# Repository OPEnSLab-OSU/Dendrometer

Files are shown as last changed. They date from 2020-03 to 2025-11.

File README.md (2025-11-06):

<p align="center">
    
  </a>
</p>

<h3 align="center">Dendrometer</h3>



## Introduction
The Dendrometer is an ongoing project that strives to enable ecological researchers and/or care-takers of grape plants to be able to effectively measure diurnal fluctuations in grape vines. Such information can be crucial for producing market-ideal grapes, as the shrinkage and growth of the vines are important indicators of when the plant is in need of water. Learn more about the design and outcomes on our <a href="https://github.com/OPEnSLab-OSU/OPEnS-Lab-Home/wiki/Dendrometer">Dendrometer Lab Wiki</a>. 

## Key Features
  - Data is collected and written to a SD card every 15 minutes, allowing the system to operate for long durations without human intervention
  - Devices can wirelessly report data back to a remote server by communicating with an internet-connected "hub" device
  - Magnetic encoder ([AS5311](https://ams.com/documents/20143/36005/AS5311_DS000200_2-00.pdf)) has a resolution of ~488nm with an extremely low temperature dependency (ideal for outdoor use)
  - Integration with [Loom](https://github.com/OPEnSLab-OSU/Loom-V4), which will allow this device to support plug-and-play functionalities with integrated sensors

## Directory 
### PCB: 
Printed circuit board (PCB) design files for the nodes. 
### src: 
Contains all of the code used on the dendrometer.
LoRa: Contains the source code for the node sensors and the LTE hub. This uses LoRa batch uploading which will upload all of the collected data at set intervals.
LoRa Non Batch: Contains the source code for the node sensors and the LTE hub. This will only upload ONE packet of data at set intervals. All of the data is still saved on SD card.
WiFi: Contains the source code for the WiFi connected nodes.

## Relevant Documents
* [User Manual](https://docs.google.com/document/d/1OHKa2jYamG2kPEfxrQMzi3MNHZGgkPIG/)
* [HardwareX Paper](https://www.sciencedirect.com/science/article/pii/S246806722100078X)
* [Troubleshooting Guide](https://docs.google.com/document/d/1E4zUMmSh5PVmP7RXUqQrh7S9IGuxQKPj5EQ5KcT2HYE/edit?usp=sharing)
* [Mechanical Assembly Guide](https://docs.google.com/document/d/1LzM_XnqVP9GkIqY2_pnTvdrFFe5u78ZPXJizvT70y4o/edit?usp=sharing)
* [Electronics Assembly Guide](https://docs.google.com/document/d/1BaNuNSJrL86lxKixB8chgZGySgj0bhYSMtVzJu6EDW4/edit?usp=sharing)
* [MongoDB Dashboard Guide](https://docs.google.com/document/d/1PlT9hrC62OXXhL8AD17e3FiPCwlHFJaZIvXCRnmihIE/edit?usp=sharing)
* [Installation Guide (Outdated)](https://docs.google.com/document/d/1GR2qeMWASApCwk-RbZwvsvWmB1qEz0QU8RcxwjgoDQY/edit?usp=sharing)

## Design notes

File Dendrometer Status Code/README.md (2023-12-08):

# DendrometerStatus
This code was written by Dajeong Kim from UBC team. This code connects to MongoDB and sends email reports of alignment, battery status, and data point plots

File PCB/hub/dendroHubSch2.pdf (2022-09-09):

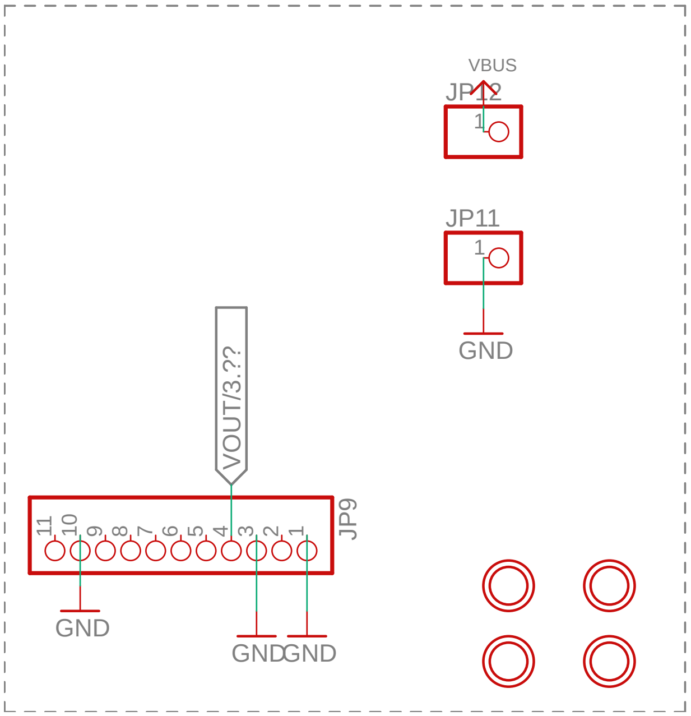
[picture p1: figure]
GND; GNDGND; VBUS 1110; JP12 VOUT/3.??

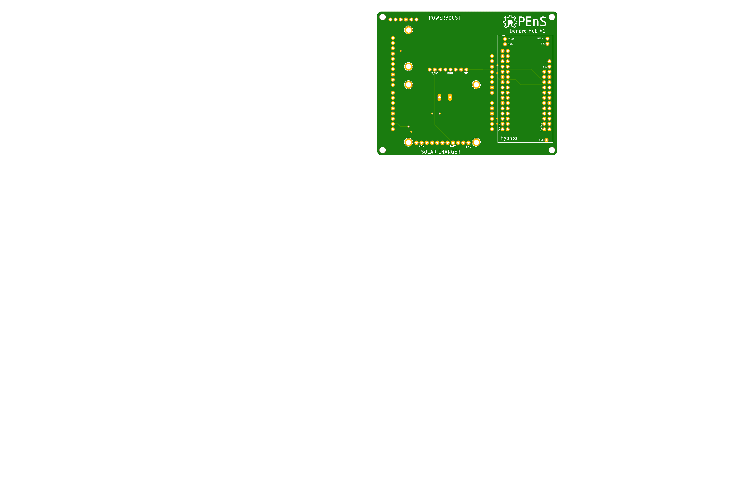
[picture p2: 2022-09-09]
PCB/hub/dendHub_top.png

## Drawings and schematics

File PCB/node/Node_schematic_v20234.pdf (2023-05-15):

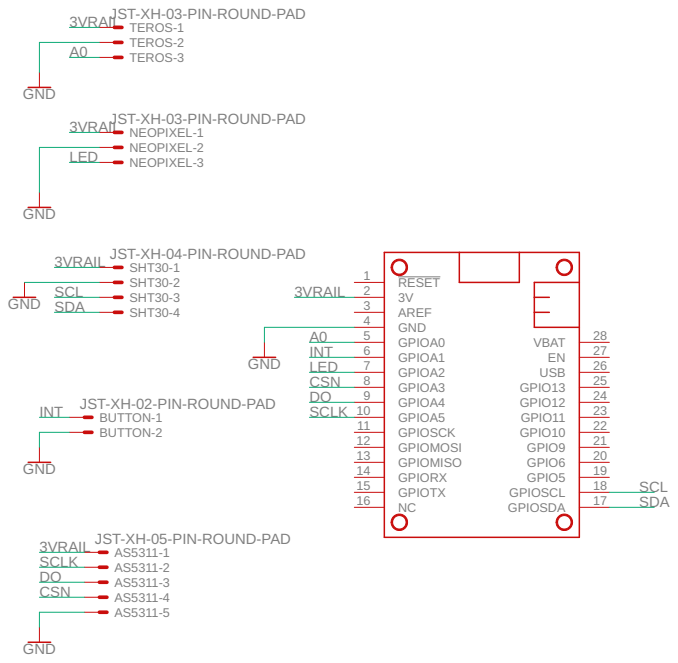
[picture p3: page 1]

JST-XH-03-PIN-ROUND-PAD
TEROS-1
TEROS-2
TEROS-3

NEOPIXEL-1
NEOPIXEL-2
NEOPIXEL-3

JST-XH-02-PIN-ROUND-PAD
BUTTON-1
BUTTON-2

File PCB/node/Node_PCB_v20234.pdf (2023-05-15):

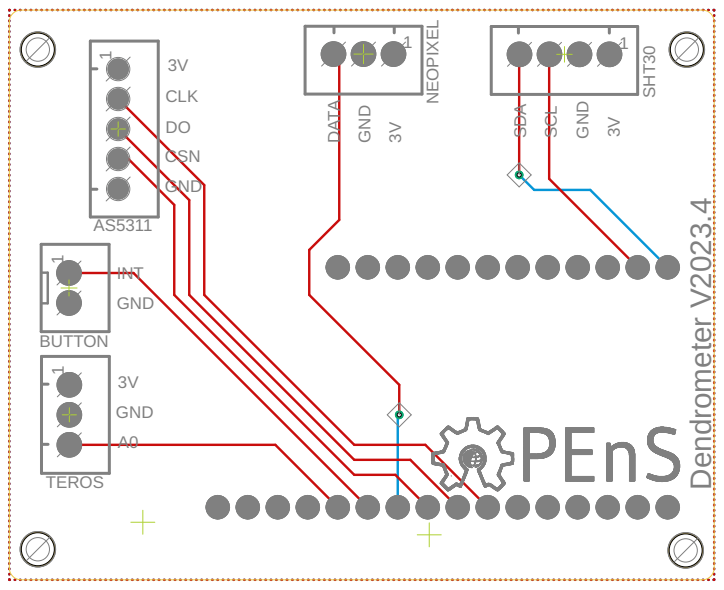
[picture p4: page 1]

Dendrometer V2023.4 1 1 1 1 1 GND GND GND INT 3V3V DATA SCL SDA GND CSN DOCLK 3V GND A03V BUTTON NEOPIXEL SHT30 AS5311 TEROS

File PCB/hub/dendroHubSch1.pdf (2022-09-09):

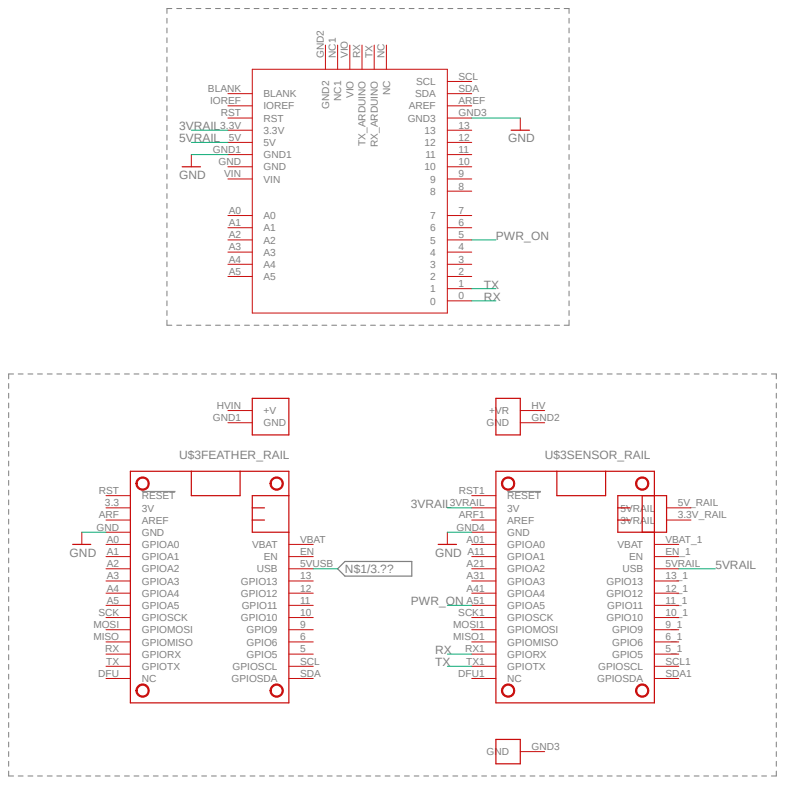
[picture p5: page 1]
GND; BLANK BLANK; IOREF IOREF; RST RST; GND1 GND1; GND GND; VIN VIN; GND² GND² NC¹ NC¹ VIO VIO TX_ARDUINO RX RX_ARDUINO TX NC NC; SCL; SCL SDA; SDA; AREF; AREF GND3; GND3; 0 RESET RST; AREF ARF; EN GND GND; GPIO5; 5 GPIO6; 6 GPIO9; 9 GPIO10; 10 GPIO11; 11 GPIO12; 12 GPIO13; 13 GPIOA0 A0; GPIOA1 A1; GPIOA2 A2; GPIOA3 A3; GPIOA4 A4; GPIOA5 A5; GPIOMISO MISO; GPIOMOSI MOSI; GPIORX RX; GPIOSCK SCK; GPIOSCL; SCL GPIOSDA; SDA GPIOTX TX; NC DFU; USB; 5VUSB; VBAT; VBAT U$3FEATHER_RAIL; RESET RST1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

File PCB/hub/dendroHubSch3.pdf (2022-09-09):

# JP1 N$1/1.?? VOUT/2.??

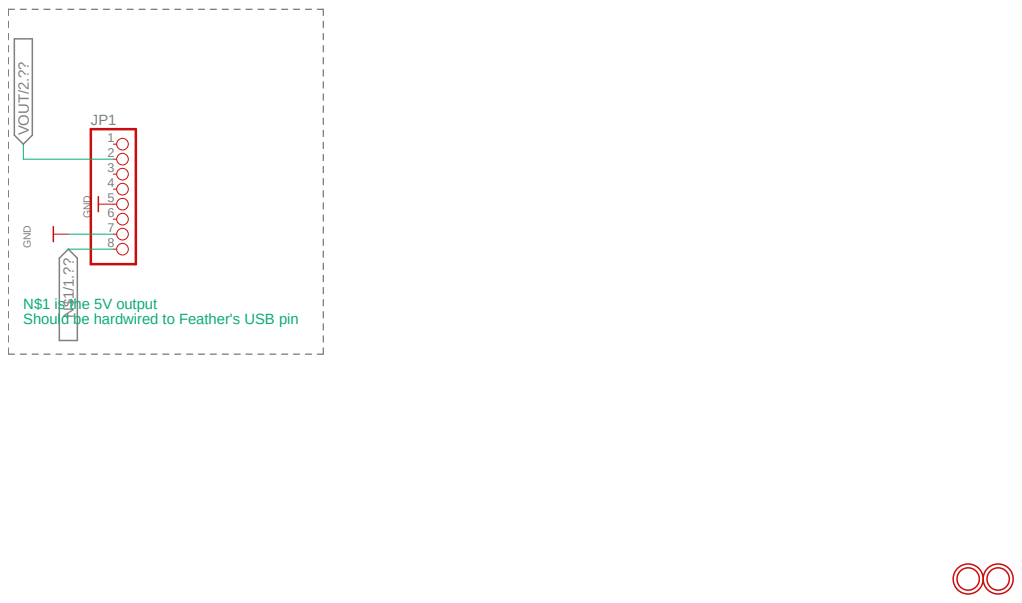
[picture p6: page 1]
GND GND

N$1 is the 5V output
Should be hardwired to Feather's USB pin

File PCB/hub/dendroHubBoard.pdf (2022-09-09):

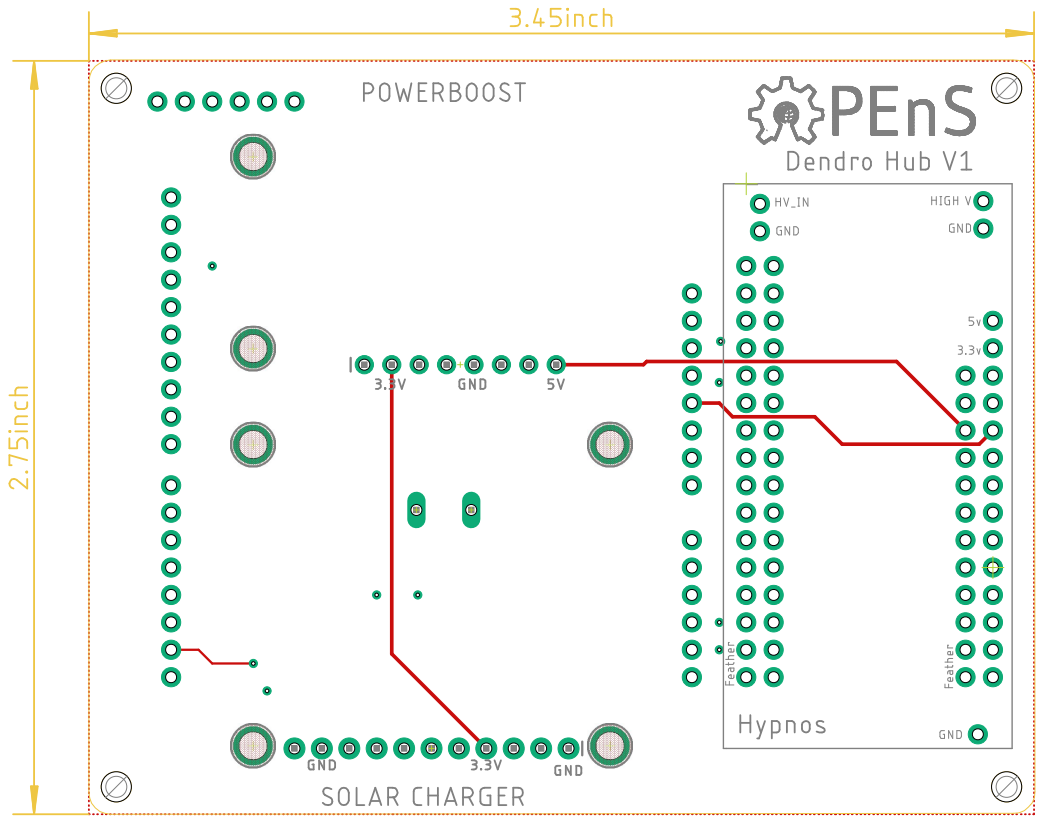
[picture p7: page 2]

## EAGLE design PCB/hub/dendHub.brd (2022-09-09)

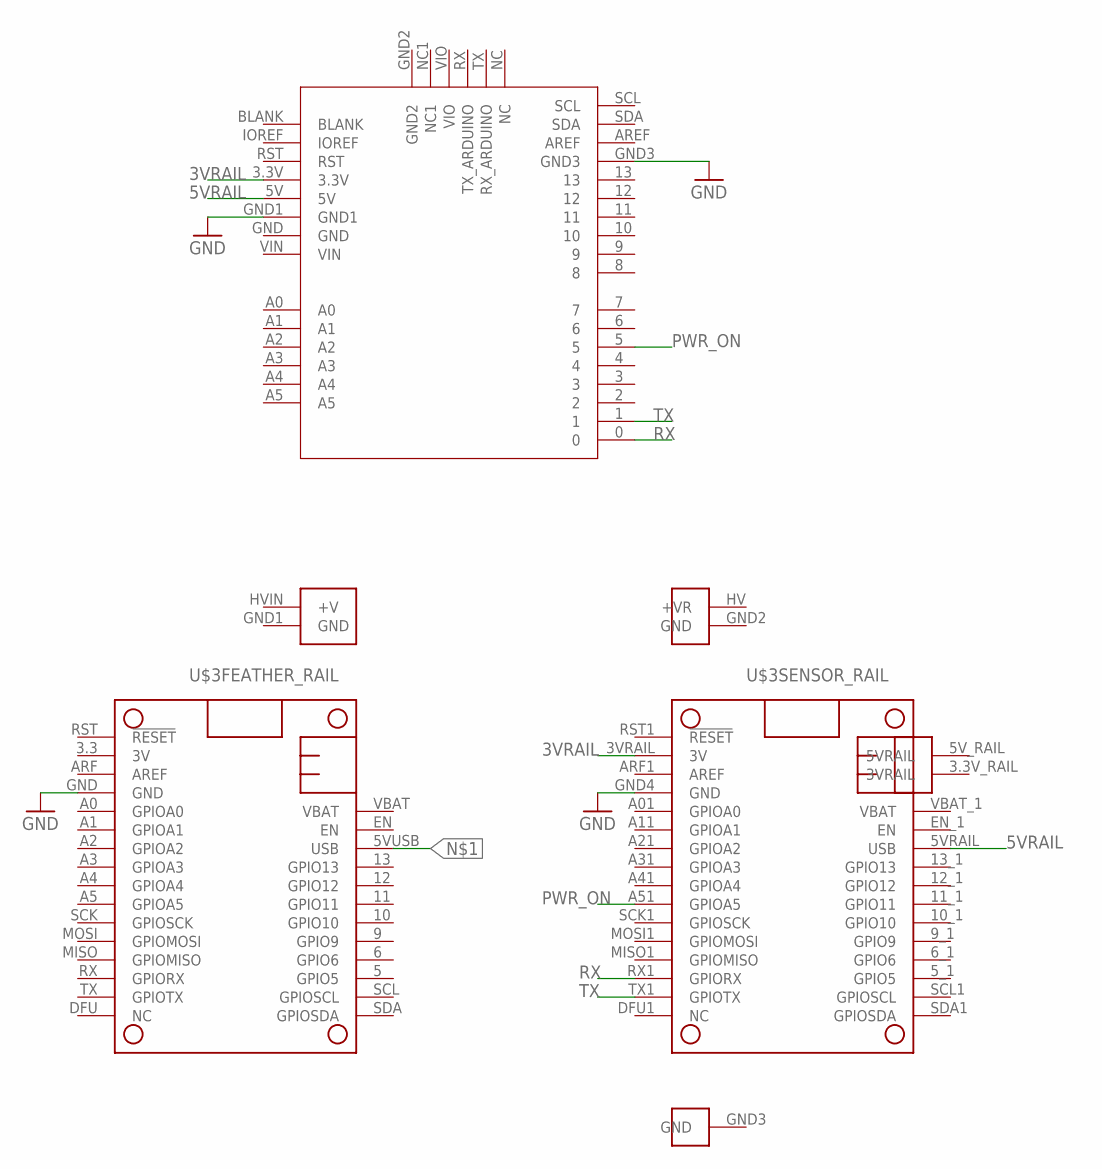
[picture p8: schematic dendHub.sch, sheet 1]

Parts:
U$1: LTE_BOARD; LTE_BOARD_FOOTPRINT
U$3: HYPNOS_V3

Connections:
3VRAIL: U$1.3.3V, U$3.3VRAIL (3V)
5VRAIL: U$1.5V, U$3.5VRAIL (USB)
GND: U$1.GND1, U$1.GND3, U$3.GND, U$3.GND4 (GND); also elsewhere on the board
unnamed 3: U$3.5VUSB (USB); also elsewhere on the board
PWR_ON: U$1.5, U$3.A51 (GPIOA5)
RX: U$1.0, U$3.RX1 (GPIORX)
TX: U$1.1, U$3.TX1 (GPIOTX)

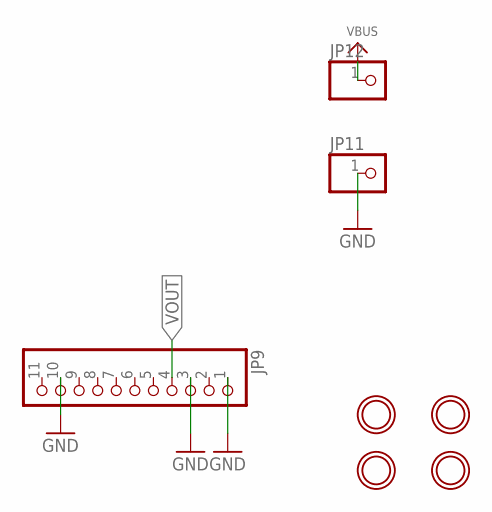
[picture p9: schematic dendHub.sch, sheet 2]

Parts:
JP9: HEADER-1X1176MIL; 1X11_ROUND_76
JP11, JP12: HEADER-1X1; 1X01_OVAL
U$45, U$46, U$47, U$48: MOUNTINGHOLE2.5; MOUNTINGHOLE_2.5_PLATED

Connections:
GND: JP9.1, JP9.3, JP9.10, JP11.1; also elsewhere on the board
VBUS: JP12.1
VOUT: JP9.4; also elsewhere on the board

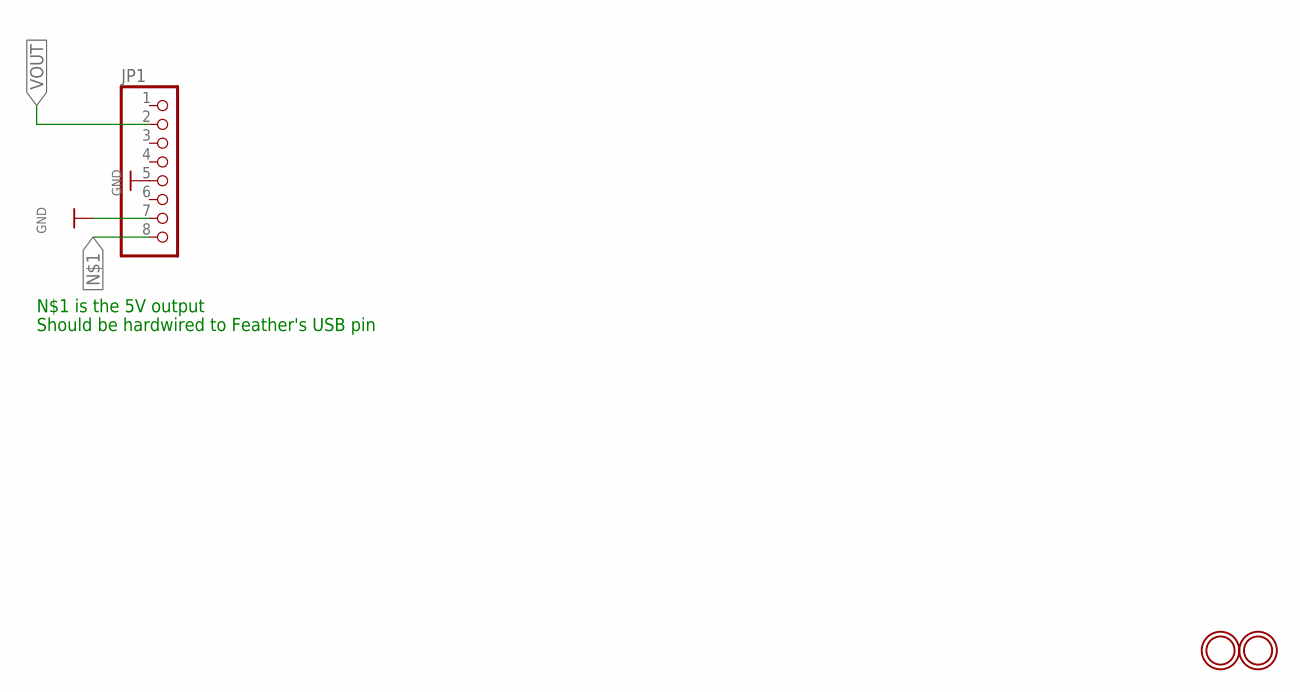
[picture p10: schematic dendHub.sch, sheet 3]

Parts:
JP1: HEADER-1X8ROUND; 1X08_ROUND
U$56, U$57: MOUNTINGHOLE2.5; MOUNTINGHOLE_2.5_PLATED

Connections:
GND: JP1.5, JP1.7; also elsewhere on the board
unnamed 3: JP1.8; also elsewhere on the board
VOUT: JP1.2; also elsewhere on the board

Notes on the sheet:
N$1 is the 5V output
Should be hardwired to Feather's USB pin

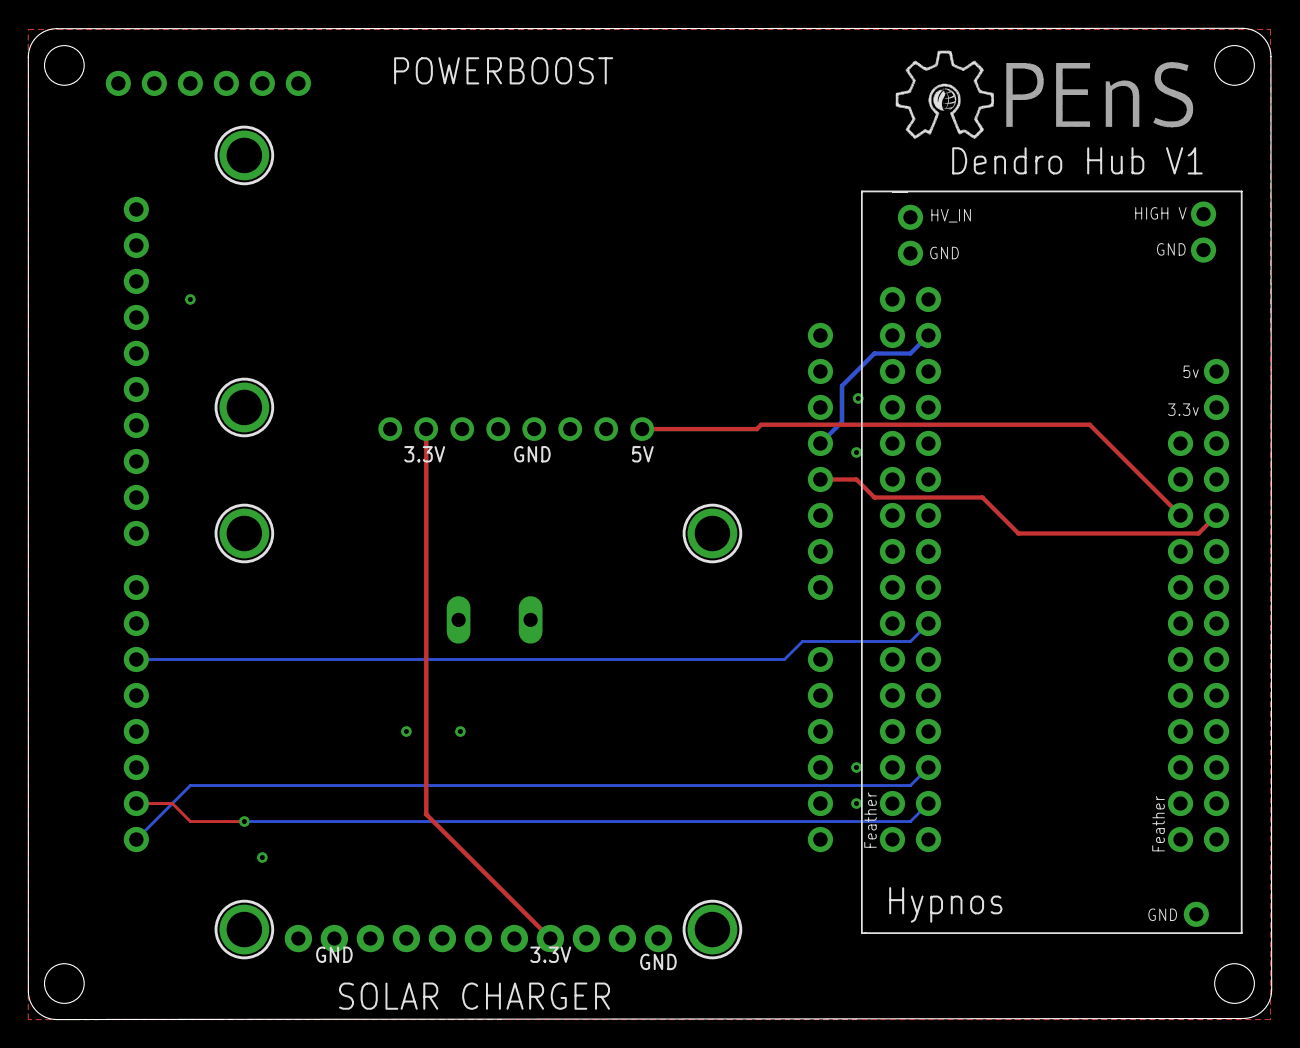
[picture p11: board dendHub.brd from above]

Board: 2 copper layers, 87.7 x 69.9 mm, 13 parts (1 on the bottom side), 8 nets.

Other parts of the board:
U$2: OPENS-LOGO

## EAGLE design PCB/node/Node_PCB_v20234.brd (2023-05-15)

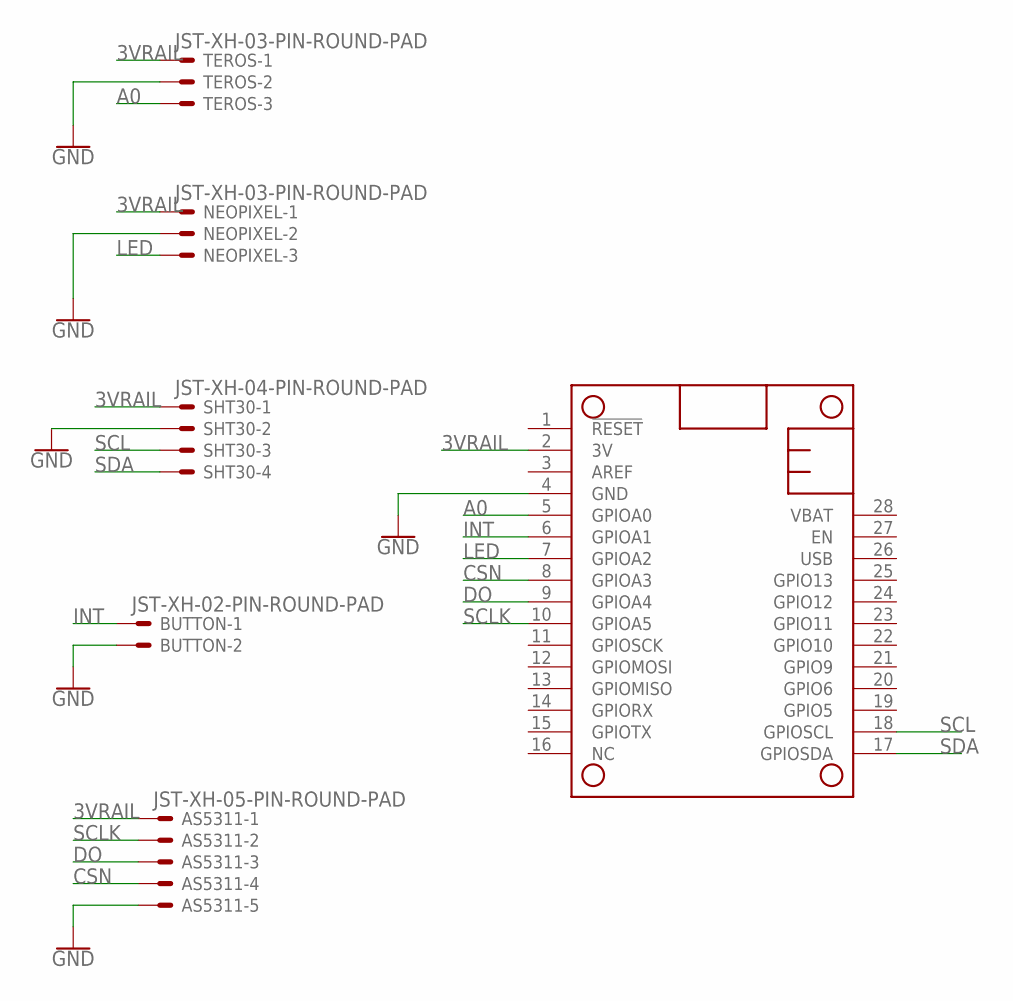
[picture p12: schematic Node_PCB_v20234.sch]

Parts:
AS5311: JST-XH-05-PIN-ROUND-PAD; JST-XH-05-PACKAGE-ROUND-PAD
BUTTON: JST-XH-02-PIN-ROUND-PAD; JST-XH-02-PACKAGE-ROUND-PAD
MS1: FEATHERWING
NEOPIXEL: JST-XH-03-PIN-ROUND-PAD; JST-XH-03-PACKAGE-ROUND-PAD
SHT30: JST-XH-04-PIN-ROUND-PAD; JST-XH-04-PACKAGE-ROUND-PAD
TEROS: JST-XH-03-PIN-ROUND-PAD; JST-XH-03-PACKAGE-ROUND-PAD

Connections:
3VRAIL: AS5311.1, MS1.2 (3V), NEOPIXEL.1, SHT30.1, TEROS.1
A0: MS1.5 (GPIOA0), TEROS.3
CSN: AS5311.4, MS1.8 (GPIOA3)
DO: AS5311.3, MS1.9 (GPIOA4)
GND: AS5311.5, BUTTON.2, MS1.4 (GND), NEOPIXEL.2, SHT30.2, TEROS.2
INT: BUTTON.1, MS1.6 (GPIOA1)
LED: MS1.7 (GPIOA2), NEOPIXEL.3
SCL: MS1.18 (GPIOSCL), SHT30.3
SCLK: AS5311.2, MS1.10 (GPIOA5)
SDA: MS1.17 (GPIOSDA), SHT30.4

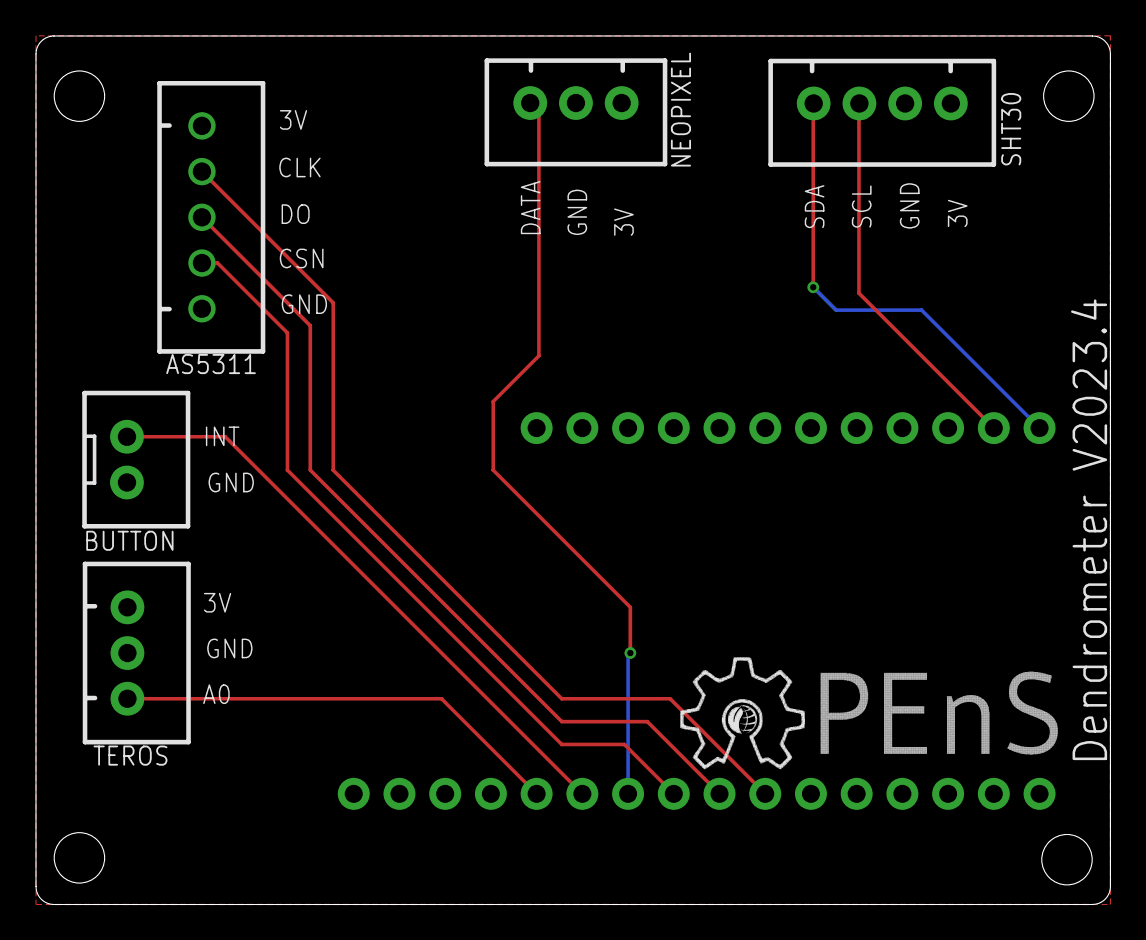
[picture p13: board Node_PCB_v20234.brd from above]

Board: 2 copper layers, 59.7 x 48.2 mm, 7 parts (0 on the bottom side), 10 nets.

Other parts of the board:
U$1: OPENS-LOGO

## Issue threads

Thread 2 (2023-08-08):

BB2 Screw/Nut on Wishbone sometimes causes issues if it touches the AS5311 board

nicholasqle, 2023-08-08:
**Describe the bug**
On one magnet sensor used, I found that there was odd behavior if the nut was touching the board. The dendrometer would be stuck on but would not function. The red lights on the feather board and the Hypnos board would all be illuminated, except for the status LED. When this happens, the device will be stuck like this and is not visible in Arduino IDE until it is reset. The device will continue working normally after the reset and the wishbone is moved off of the magnet sensor.
**Hardware in Use**
A list of all hardware currently in use
Blueberry dendrometer 2
Magnet sensor

**To Reproduce**
Steps to reproduce the behavior:
1. Position wishbone so the nut is touching the board.
2. Plug magnet sensor into Dendrometer.
3. Power on Dendrometer

**Expected behavior**
The device should be able to function normally. Perhaps better insulation on the magnet sensor is needed to prevent shorts?

nicholasqle, 2025-04-23:
**Description of steps taken to resolve them:**

- Cut solder to be more flush with sensor board
- Ensure adequete conformal coating on board to prevent shorting

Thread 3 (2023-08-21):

Timestamp issues

ejdautel, 2023-08-21:
The timestamp on some datasets are incorrect. The time will return to a certain date/time and the package number will change. UBC has consistent issues with this.

some potential causes could be the coin cell battery or the actual firmware code? I know Chet and Will were actively working on this issue, so if you could share progress we can inform UBC as well!

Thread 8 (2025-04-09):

Alignment button not responding

nicholasqle, 2025-04-09:
Date issue was identified:
2/2/2025
Who identified issue: 		Lars Rasmussen
Description of sensor model with issue: Retrofitted single spring dendrometer with 3d printed spring holder and old 1040 pelican case
Client with issue: Biosphere
Device Name: Bio8

**Description of error or issue that occurred:**
Sensor was in good working order, battery was charged, reporting through wifi was good, then alignment LED was not responding with red/yellow/green indicators when button was pressed. MongoDB Data shows that the sensor was still taking measurements but the LED was still not responding, no reported moisture damage inside case when client was asked to check, restarting the device did not resolve the issue.

**Description/list of what could be causing this issue:**

- LED is broken
- Button is broken
- Something wrong with software

**Description of steps taken to resolve them:**
The LED and button were removed and tested after the client shipped the sensor back to the lab, after testing it was found that the button was functional but the LED had gone bad. After replacing the LED and a week of running the sensor in the lab, the LED seems to be responding as intended.

**Fixed or still ongoing? Possible solutions to prevent this on future models.**

- Problem fixed and tested, sensor shipped back on 2/22/25
- Researching why LEDs might go bad, exploring other LED options if this continues in the future

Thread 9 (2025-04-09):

SD Card Failure causing data loss and unable to connect to network to upload

nicholasqle, 2025-04-09:
Date issue was identified: 	2025

Who identified issue: 		Nicholas Le

Description of sensor model with issue: 2023 Build dendrometers in 1050 cases.

Client with issue: Draga and UBC

Device Name:

**Description of error or issue that occurred:**
Data will no longer be logged on SD card or reading data from SD card is corrupt or not possible. This can cause loss of data or on the WiFi devices, being unable to connect and upload as the credentials need to be read from the SD card. Sometimes the SD card will not initialize at all.

**Description/list of what could be causing this issue:**

-Weather, heat, humidity or general wear causes the SD card to fail
-Hardware failure

**Description of steps taken to resolve them:**
-We replaced all of the sd cards on Draga devices in 2025 with [industrial SD cards](https://www.amazon.com/SanDisk-Industrial-MicroSDHC-SDSDQAF3-008G-I-Everything/dp/B085GL4LTQ?sr=8-2) which should be able to handle more extreme environments.
-Replacing the hypnos board on the UBC device 15 in March 2025 fixed an issue with initializing the SD card.
**Fixed or still ongoing? Possible solutions to prevent this on future models.**
Issue has been fixed for now but it remains to be seen whether the industrial SD cards will last longer

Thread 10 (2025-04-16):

LTE board disconnects from network

nicholasqle, 2025-04-16:
Date issue was identified:
2023
Who identified issue: 	Connor M

Description of sensor model with issue:
Hubs with SparkFun LTE Cat M1/NB-IoT Shield
Client with issue:
Draga
Device Name:
Hazelnut_hub and occasionally LB_hub
**Description of error or issue that occurred:**
Device disconnects from network. This is seen by the blue network light going out at some point during operation. Range of this occuring can be either at first startup or even weeks into a deployment.
**Description/list of what could be causing this issue:**

- Weak connection
- Some underlying issue with the Sara R410 or board
-

**Description of steps taken to resolve them:**
-Used external antenna connected to UFL. (This seemed to reduce the occurance of this problem but it still happens occasionally.
-Swap LTE board
-Forward issues to Loom team
-Used m-center program to try different AT codes and settings
-Contacted Ublox for latest firmware and Easyflash software to flash updated firmware to R410

**Fixed or still ongoing? Possible solutions to prevent this on future models.**
Still ongoing. Possibly look into using different LTE modem.

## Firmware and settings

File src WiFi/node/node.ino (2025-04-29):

#include <Loom_Manager.h> //4.6
#include <Hardware/Loom_Hypnos/Loom_Hypnos.h>
#include <Hardware/Actuators/Loom_Neopixel/Loom_Neopixel.h>
#include <Sensors/Loom_Analog/Loom_Analog.h>
#include <Sensors/Analog/Loom_Teros10/Loom_Teros10.h>
#include <Sensors/I2C/Loom_SHT31/Loom_SHT31.h>

#include <Internet/Connectivity/Loom_Wifi/Loom_Wifi.h>
#include <Internet/Logging/Loom_MongoDB/Loom_MongoDB.h>

#include "AS5311.h"

//////////////////////////
/* DEVICE CONFIGURATION */
//////////////////////////
static const uint8_t NODE_NUMBER = 1;
static const char * DEVICE_NAME = "HazelnutDendrometer_";
////Select one wireless communication option

#define DENDROMETER_WIFI

TimeSpan sleepInterval;
static const uint8_t TRANSMIT_INTERVAL = 16; // to save power, only transmit every X measurements
////Use teros 10?
//#define DENDROMETER_TEROS10
//////////////////////////
//////////////////////////

// Pins
#define AS5311_CS A3 // 9 for LB version, A3 otherwise
#define AS5311_CLK A5
#define AS5311_DO A4
#define BUTTON_PIN A1 // 11 for LB, A1 otherwise

// Loom
Manager manager(DEVICE_NAME, NODE_NUMBER);
Loom_Hypnos hypnos(manager, HYPNOS_VERSION::V3_3, TIME_ZONE::PST); // 3_2 for LB, 3_3 otherwise
// Loom Sensors
Loom_Analog analog(manager);
#ifdef DENDROMETER_TEROS10
Loom_Teros10 teros(manager, A0);
#endif
Loom_SHT31 sht(manager);
Loom_Neopixel statusLight(manager, false, false, true, NEO_GRB); // using channel 2 (physical pin A2). use RGB for through-hole LED devices. GRB otherwise.

// magnet sensor
AS5311 magnetSensor(AS5311_CS, AS5311_CLK, AS5311_DO);

// wireless
#if defined DENDROMETER_WIFI
#include "arduino_secrets.h"
Loom_WIFI wifi(manager, CommunicationMode::CLIENT, SECRET_SSID, SECRET_PASS);
Loom_MongoDB mqtt(manager, wifi, SECRET_BROKER, SECRET_PORT, MQTT_DATABASE, BROKER_USER, BROKER_PASS);
Loom_BatchSD batchSD(hypnos, TRANSMIT_INTERVAL);
#else
#warning Wireless communication disabled!
#endif

// Global Variables
volatile bool buttonPressed = false; // Check to see if button was pressed

void sleepCycle();
void ISR_RTC();
void ISR_BUTTON();

void measure();
void measureVPD();
void transmit();

void setRTC(bool);
void checkMagnetSensor();
void alignMagnetSensor();
bool checkStableAlignment();
void displayMagnetStatus(magnetStatus);
void flashColor(uint8_t r, uint8_t g, uint8_t b);

/**
 * Program setup
 */
void setup()
{

    pinMode(BUTTON_PIN, INPUT_PULLUP); // Enable pullup on button pin. this is necessary for the interrupt (and the button check on the next line)
    delay(10);
    bool userInput = !digitalRead(BUTTON_PIN); // wait for serial connection ONLY button is pressed (low reading)
    manager.beginSerial(userInput);            // wait for serial connection ONLY button is pressed
    
    hypnos.setLogName("HazelnutDendrometer_1data"); //SD card CSV file name
    hypnos.enable();
    sleepInterval = hypnos.getConfigFromSD("HypnosConfig.json");

#if defined DENDROMETER_WIFI
    wifi.setBatchSD(batchSD);
    wifi.setMaxRetries(2);
    mqtt.setMaxRetries(2);
    wifi.loadConfigFromJSON(hypnos.readFile("wifi_creds.json"));
    mqtt.loadConfigFromJSON(hypnos.readFile("mqtt_creds.json"));
    hypnos.setNetworkInterface(&wifi);
#endif
    manager.initialize();
    setRTC(userInput);

    checkMagnetSensor();
    alignMagnetSensor();

    hypnos.registerInterrupt(ISR_RTC);
}

/**
 * Main loop
 */
void loop()
{
    measure();
    if (buttonPressed) // if interrupt button was pressed, display staus of magnet sensor
    {
        displayMagnetStatus(magnetSensor.getMagnetStatus());
        delay(3000);
        statusLight.set_color(2, 0, 0, 0, 0); // LED Off
        buttonPressed = false;
    }
    transmit();
    sleepCycle();
}

/**
 * Perform all measurements for the dendrometer and put them into a packet.
 * Log to SD card.
 */
void measure()
{
    manager.measure();
    manager.package();

    measureVPD();
    magnetSensor.measure(manager);
    // Log whether system woke up from button or not
    manager.addData("Button", "Pressed?", buttonPressed);

    hypnos.logToSD();

    // delay(5000);
    // manager.display_data();
}

/**
 * Log readings from the SHT31 sensor. Also calculate and log VPD.
 */
void measureVPD()
{
    float SVP, VPD, temperature, humidity;
    float e = 2.71828;

    temperature = sht.getTemperature();
    humidity = sht.getHumidity();

    // Tetens equation
    SVP = (0.61078 * pow(e, (17.2694 * temperature) / (temperature + 237.3)));
    VPD = SVP * (1 - (humidity / 100));

    manager.addData("SHT31", "VPD", VPD);
}

/**
 * transmit the batch data packet 
 */
void transmit()
{
#if defined DENDROMETER_WIFI
    if (!batchSD.shouldPublish())
    {
        char output[100];
        snprintf_P(output, OUTPUT_SIZE, PSTR("<Dendrometer> Not ready to publish. Currently at packet %i of %i"),
                   batchSD.getCurrentBatch(), batchSD.getBatchSize());
        Serial.println(output);
    }
    if (wifi.isConnected())
        hypnos.networkTimeUpdate();
        mqtt.publish(batchSD);
#endif
}

/**
 * Shut down the device for a specified time period to save power.
 */
void sleepCycle()
{
    hypnos.setInterruptDuration(sleepInterval);
    // Reattach to the interrupt after we have set the alarm so we can have repeat triggers
    hypnos.reattachRTCInterrupt();
    attachInterrupt(digitalPinToInterrupt(BUTTON_PIN), ISR_BUTTON, FALLING);

    // Put the device into a deep sleep, operation HALTS here until the interrupt is triggered
    hypnos.sleep();
    detachInterrupt(digitalPinToInterrupt(BUTTON_PIN));
}

// Interrupt routines
void ISR_RTC()
{
    hypnos.wakeup();
}

void ISR_BUTTON()
{
    buttonPressed = true;
    hypnos.wakeup();
}

/**
 * Magnet alignment procedure. Displays magnet sensor to user until
 * the magnet is determined to be properly aligned and maintains that alignment
 * for a certain amount of time
 */
void alignMagnetSensor()
{
    magnetStatus status;

    Serial.println(F("<Dendrometer> Waiting for magnet alignment"));
    while (1)
    {
        // Watchdog.reset();
        status = magnetSensor.getMagnetStatus();
        displayMagnetStatus(status);
        delay(100);
        if (status == magnetStatus::green && checkStableAlignment())
            break;
    }
    flashColor(0, 255, 0);
}

/**
 * Check the magnet sensor alignment status and display it on the multi-color LED
 * @param   status  the magnetStatus to display
 */
void displayMagnetStatus(magnetStatus status)
{
    switch (status)
    {
    case magnetStatus::yellow:
        statusLight.set_color(2, 0, 255, 100, 0); // yellow
        break;
    case magnetStatus::green:
        statusLight.set_color(2, 0, 0, 255, 0); // green
        break;
    case magnetStatus::error: // Fall through
    case magnetStatus::red:   // Fall through
    default:
        statusLight.set_color(2, 0, 255, 0, 0); // red
        break;                                  // do nothing
    }
}

/**
 * Flashes status light
 * @param   r   red color value (unsigned 8 bit number)
 * @param   g   green color value (unsigned 8 bit number)
 * @param   b   blue color value (unsigned 8 bit number)
 */
void flashColor(uint8_t r, uint8_t g, uint8_t b)
{
    for (auto _ = 6; _--;)
    {
        // Watchdog.reset();
        statusLight.set_color(2, 0, r, g, b);
        delay(250);
        statusLight.set_color(2, 0, 0, 0, 0); // off
        delay(250);
    }
}

/**
 * Make sure calibration is stable before proceeding
 * Returns true if the sensor remains aligned for the next five seconds
 */
bool checkStableAlignment()
{
    const unsigned int CHECK_TIME = 3000;
    magnetStatus status;
    bool aligned = true;

    for (int i = 0; i < (CHECK_TIME / 100); i++)
    {
        // Watchdog.reset();
        status = magnetSensor.getMagnetStatus();
        if (status != magnetStatus::green)
        {
            aligned = false;
            break;
        }
        delay(100);
    }

    return aligned;
}

/**
 * Checks to see if a magnet sensor is connected and functioning.
 */
void checkMagnetSensor()
{
    uint32_t data = magnetSensor.getRawData();
    if (__builtin_parity(data) == 0 && data != 0) //__builtin_parity() returns 0 if value has even parity
        return;
    for (auto _ = 6; _--;)
        flashColor(255, 100, 0); // if the check didn't pass, alert the user by flashing the LED
}

/**
 * Ask the user to set a custom time
 */
void setRTC(bool wait)
{
    if (!wait || !Serial)
        return;

    Serial.println(F("<Dendrometer> Adjust RTC time? (y/n)"));
    while (!Serial.available())
        ;
    int val = Serial.read();
    delay(50);
    while (Serial.available())
        Serial.read(); // flush the input buffer to avoid invalid input to rtc function

    if (val == 'y')
    {
        hypnos.set_custom_time();
    }
}

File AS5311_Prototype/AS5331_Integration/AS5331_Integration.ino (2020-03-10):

#include <WiFi101.h>
#include "AS5331.h"
#include "gsheets.h"
#include "config.h"
#include "vector"
#include <Loom.h>
#include <stdint.h>

const char* config = 
#include "loomconfig.h"
;

#define CS 9
#define CLK A5
#define DO A4
#define PULSE 11

LoomFactory<
	Enable::Internet::Disabled,
	Enable::Sensors::Enabled,
	Enable::Radios::Disabled,
	Enable::Actuators::Disabled,
	Enable::Max::Disabled
> ModuleFactory{};

LoomManager Loom{ &ModuleFactory };


GSheets api(clientID, clientSecret, refreshToken, sheetID);

int i = 1;
String currTime;

uint32_t start = 0;
uint32_t prevTwoSig = 0;
float elapsed = 0;


void setup() {
  pinMode(5, OUTPUT);
  digitalWrite(5, LOW); // Sets pin 5, the pin with the 3.3V rail, to output and enables the rail
  pinMode(6, OUTPUT);
  digitalWrite(6, HIGH); // Sets pin 6, the pin with the 5V rail, to output and enables the rail

  Loom.begin_serial(true);
  Loom.parse_config(config);
  Loom.print_config();
    
  pinMode(CS, OUTPUT);
  pinMode(CLK, OUTPUT);
  pinMode(DO, INPUT_PULLDOWN);
  digitalWrite(CS, HIGH);
  digitalWrite(CLK, LOW);

  Loom.pause();

  
  WiFi.setPins(8, 7, 4, 2);
    WiFi.begin(ssid);
    while (WiFi.status() != WL_CONNECTED) {
      Loom.pause();
      Serial.println("Connecting to WiFi..");
    }
    Serial.println("Connected to the WiFi network");


    int i = 1;
    String currTime;

    start = bitbang(CLK, CS, DO);
    start = convertBits(start);
    prevTwoSig = start & 0xC00;

    // Create header for Google Sheet Table
    // std::vector<std::vector<String>> header = {{"Time", "Control Temp", "Value", "Actual Temp", "Humidity"}};
    // api.updateSheet("Sheet1!A1:E1", header, PARSED);
}

void loop() {

    Loom.measure();
    Loom.package();
    // Loom.display_data();
    Loom.pause();


  delay(2000); //Sensing value every 5 seconds (3 + 2)
  uint32_t curr = bitbang(CLK, CS, DO);
  curr = convertBits(curr);
  uint32_t currTwoSig = curr & 0xC00;
  if((currTwoSig == 0xC00 && prevTwoSig == 0x0)) {
    Serial.println("ROLLOVER UNDERFLOW");
    elapsed -= 2.0;
  } else if (prevTwoSig == 0xC00 && currTwoSig == 0x0) {
    Serial.println("ROLLOVER OVERFLOW");
    elapsed += 2.0;
  }
  Serial.print("Current value");
  Serial.println(curr);

  float distance = (elapsed + ((2.0 * ((int) curr - (int) start))/4095.0));
  Serial.print("Total distance: ");
  Serial.print(distance);

  
  prevTwoSig = currTwoSig;


  // Getting Serial data
  //    x16 for average
  int average = 0;

  for(int j = 0; j < 16; j++)
  {
    uint32_t value = bitbang(CLK, CS, DO);
    uint32_t readval = value & 0xFFF;
    uint32_t newval = 0;
    for (int i = 11; i >= 0; i--) 
    {
      uint32_t exists = (readval & (1 << i)) ? 1 : 0;
      newval |= (exists << (11 - i));
    }
    average += newval;
  }
  average /= 16;

  //Increment Row
  i+=1;

  //Getting Time and Date
  // TODO
  currTime = "Time";
  // 

  // Getting temperature and humidity
  // TODO
  int temp = 2;
  int humid = 2;

  //Building Google Sheet Row and sending
  // std::vector<std::vector<String>> row = {{currTime, "", String(average), String(temp), String(humid)}};
  // String a1Val = "Sheet1!A" + String(i) + ":E" + String(i);
  // api.updateSheet(a1Val, row, PARSED);

  Serial.println(average);
}

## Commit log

2019-07-12 Create Linear_Slide_4.ino
    Reads sensor data and stores on micro SD using Adalogger and RTC
2019-08-22 SHT and Voltage ref
    Added sht sensor, lm4040 voltage reference
2019-12-22 Successfully got PWM
2020-09-07 Added error checking for magnet position
2020-09-23 Added temporary magnet checker during setup
2020-10-02 Magnet checker during setup implemented
2020-11-10 Testing New Schematic Editor
    [Dendrometer.fzz]
2020-11-10 Updated Schematic for AGU
    [Dendrometer.fzz]
2020-11-13 Battery levels recorded
2020-12-06 Dendrometer PCB V1
    [DendroSchem.brd, DendroSchem.sch]
2020-12-06 PCB PDFs
2020-12-11 Added RTC PST timing and decreased LED time
2021-01-07 Added interrupt button
2021-01-29 Neopixel Interrupt
2021-01-31 Fixed Loom power rail bug
2021-02-21 Dendro PCB V1.1
    [Dendro.brd, Dendro.sch]
2021-05-04 Fixed Google Sheet bug, removed unnecessary lines
    [node.ino]
2021-06-25 Updated code + PCB for summer deployments
    [Dendro.brd, Dendro.sch]
2021-08-05 Dendrometer V1.2
    Updated PCBs for node and hub as well as includes code for both Ethernet and LTE telemetry
    [Dendro.brd, Dendro.sch, dendHub.brd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]
2021-11-04 Summer 2022 Deployment Prep
    Updated PCBs and code, includes Loom V3 and HypnosV3.3 changes
    [Dendro.brd, Dendro.sch, dendHub.brd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]
2021-12-28 Summer 2022 Deployment
    Removed BatchSD due to Loom V3 issues with publishing
    [hub.ino, node.ino]
2022-01-13 Logs whether button was pressed
2022-01-14 Updated comments, log whether system woke up from button or not
2022-09-09 File cleanup
    [Dendrometer.fzz]
2023-04-28 Fix initial position issue
    [node.ino]
2023-05-15 add RTC setup and battery voltage reporting to hub
2023-05-15 update PCB files
    [Node_PCB_v20234.brd, Node_PCB_v20234.sch, dendHub.brd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]
2023-05-15 add Teros10 sensor
2023-06-09 switch back to GRB leds
2023-12-05 Dendrometer Status Code
    Code written by Dajeong Kim from UBC team. This code connects to MongoDB and sends email reports about alignment, battery status, and scatter plots of collected data
2023-12-05 Dendrometer Status Code
    This code was written by Dajeong Kim from UBC team. This code connects to MongoDB and sends email reports of alignment, battery status, and data point plots
2023-12-05 Create Working Data Cleaning Code
    This data-cleaning code was developed by Dragomira Zheleva. The code cleans the data by extracting outliers from imported dendrometer data using interquartile ranges. The current interquartile ranges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
2023-12-11 Use raw position for displacement rather than filtered average to avoid outliers
2023-12-19 power cycle lte modem if no connection to internet
2024-01-21 Added NTP sync for internet connected devices
2024-02-03 attempt null packet fix (not working)
    [hub.ino]
2024-03-06 fixed accidentally deleting hypnos enable
    [node.ino]
2025-04-29 separated source code into separate for LoRa and WiFi devices
2025-10-08 Added parallel power board PCB gerber
2025-11-06 remove arduino_secrets
2026-03-18 Non batch LoRa naming fix
    [hub.ino]
2026-03-18 Fixed non batch transmit node code
    [node.ino]
2026-05-12 Fixed hub naming mongo upload
    [hub.ino]
2026-05-15 Added more test code, not currently working
2026-10-07 Updated PCB files to have older compiled Dendrometer 1.3 PCB and to have the hub PCB files
    [dendHub.brd, dendHub.sch]

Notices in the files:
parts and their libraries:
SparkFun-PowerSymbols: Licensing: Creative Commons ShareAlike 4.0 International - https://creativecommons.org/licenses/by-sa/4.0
